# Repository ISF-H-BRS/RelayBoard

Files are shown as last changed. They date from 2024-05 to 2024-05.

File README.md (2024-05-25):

# ISF Relay Board

## Introduction
This repository contains schematics, PCB layout, firmware and software for a circuit board providing 16 software-programmable solid-state relays with individual voltage and current monitoring, every channel capable of switching up to 2 A at 32 V. It's original purpose was to allow control of various valves and pumps for chemical processes from within a LabVIEW program but it may also be useful for other automated control tasks.

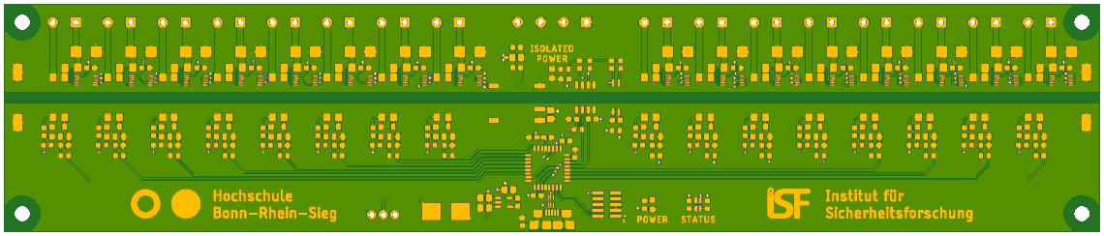
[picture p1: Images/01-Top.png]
TopView

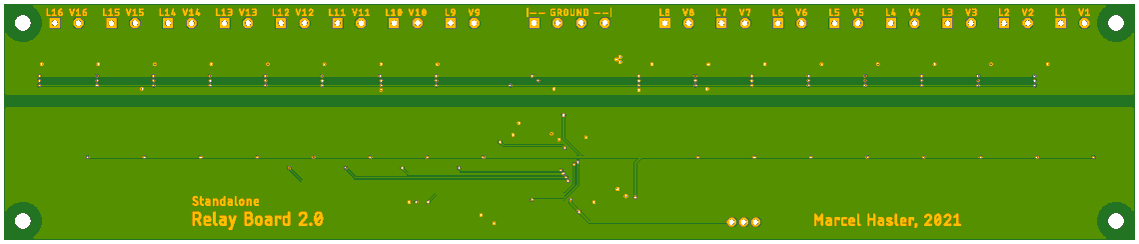
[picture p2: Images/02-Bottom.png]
BottomView


## Usage
The device uses a simple text-based protocol to communicate over a USB serial port. See Firmware/Protocol.txt for details. The protocol is also wrapped in a software library exposing both C++ and C interfaces, designed to allow it to be used from any programming language, including LabVIEW.

A Qt-based graphical example program is also provided that can be used to manually test all features of the device.

<p align="center">
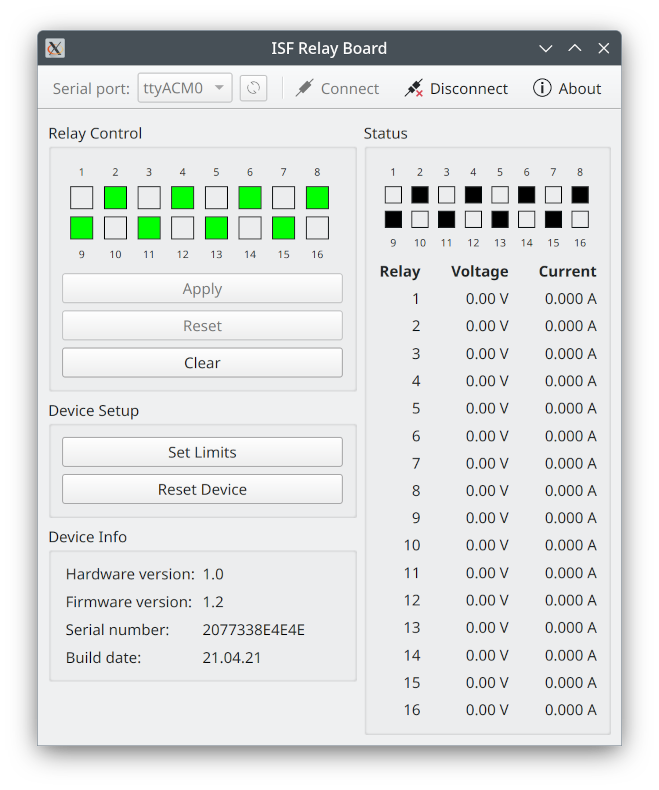
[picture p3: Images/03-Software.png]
  
</p>

## License
All source code for the software and firmware components, including the LabVIEW code, is licensed under the terms of the GNU General Public License (GPL). All schematics and layout files are licensed under the terms of the Creative Commons Attribution-ShareAlike International Public License (CC BY-SA). See COPYING in the respective subdirectories for details.

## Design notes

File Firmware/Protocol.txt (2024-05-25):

ISF RelayBoard - Communication Protocol
=======================================

Every transmission is ASCII-encoded and terminated by CR+LF (aka "\r\n").

Command Format
--------------

<COMMAND_TAG> [index] [argument1,argument2,...]

Response Format
---------------

<RESPONSE_TAG> [value1,value2,...]
or
<ERROR> code

Error Codes
-----------

DATA_OVERFLOW     Maximum transmission size of 100 characters exceeded
UNKNOWN_COMMAND   Command tag not recognized
MISSING_ARGUMENT  Insufficient number of arguments provided
INVALID_ARGUMENT  Invalid argument provided
ERASE_FAILED      Unable to erase flash memory page
WRITE_FAILED      Unable to write to flash memory

Commands
--------

RESET
Description: Resets fault and state masks
Index:       None
Arguments:   None
Example:     <RESET>
Response:    <OK>

GET_FAULT_MASK
Description: Returns bitmask (hex format) indicating overvoltage/-current
Index:       None
Arguments:   None
Example:     <GET_FAULT_MASK>
Response:    <FAULT_MASK> 0x0000

SET_RELAY_STATE
Description: Sets state of specified relay
Index:       0-15
Arguments:   New state (ON or OFF)
Examples:    <SET_RELAY_STATE> 0 ON
             <SET_RELAY_STATE> 0 OFF
Response:    <OK>

GET_RELAY_STATE
Description: Returns state of specified relay
Index:       0-15
Arguments:   None
Example:     <GET_RELAY_STATE> 0
Response:    <RELAY_STATE> OFF

SET_STATE_MASK
Description: Sets bitmask describing relay states
Index:       None
Arguments:   State mask (hex/decimal format)
Examples:    <SET_STATE_MASK> 0xaaaa
             <SET_STATE_MASK> 43690
Response:    <OK>

GET_STATE_MASK
Description: Returns bitmask (hex format) describing relay states
Index:       None
Arguments:   None
Example:     <GET_STATE_MASK>
Response:    <STATE_MASK> 0xaaaa

GET_RELAY_POWER
Description: Returns relay voltage in V and current in A
Index:       0-15
Arguments:   None
Example:     <GET_RELAY_POWER> 0
Response:    <RELAY_POWER> 12.34,1.234

SET_POWER_LIMIT
Description: Sets power limits for specified relay (max. 32 V @ 2 A)
Index:       0-15
Arguments:   Voltage limit in V, current limit in A
Example:     <SET_POWER_LIMIT> 0 16.00,1.000
Response:    <OK>

GET_POWER_LIMIT
Description: Returns currently set voltage limit in V and current limit in A
Index:       0-15
Arguments:   None
Example:     <GET_POWER_LIMIT> 0
Response:    <POWER_LIMIT> 16.00,1.000

SAVE_POWER_LIMITS
Description: Writes currently set limits to persistent flash memory
Index:       None
Arguments:   None
Example:     <SAVE_POWER_LIMITS>
Response:    <OK>

GET_HARDWARE_VERSION
Description: Returns hardware version
Index:       None
Arguments:   None
Example:     <GET_HARDWARE_VERSION>
Response:    <HARDWARE_VERSION> 1.0

GET_FIRMWARE_VERSION
Description: Returns firmware version
Index:       None
Arguments:   None
Example:     <GET_FIRMWARE_VERSION>
Response:    <FIRMWARE_VERSION> 1.0

GET_SERIAL_NUMBER
Description: Returns device serial number
Index:       None
Arguments:   None
Example:     <GET_SERIAL_NUMBER>
Response:    <SERIAL_NUMBER> 207733794E4E

GET_BUILD_TIMESTAMP
Description: Returns firmware build time as Unix time
Index:       None
Arguments:   None
Example:     <GET_BUILD_TIMESTAMP>
Response:    <BUILD_TIMESTAMP> 1618493589

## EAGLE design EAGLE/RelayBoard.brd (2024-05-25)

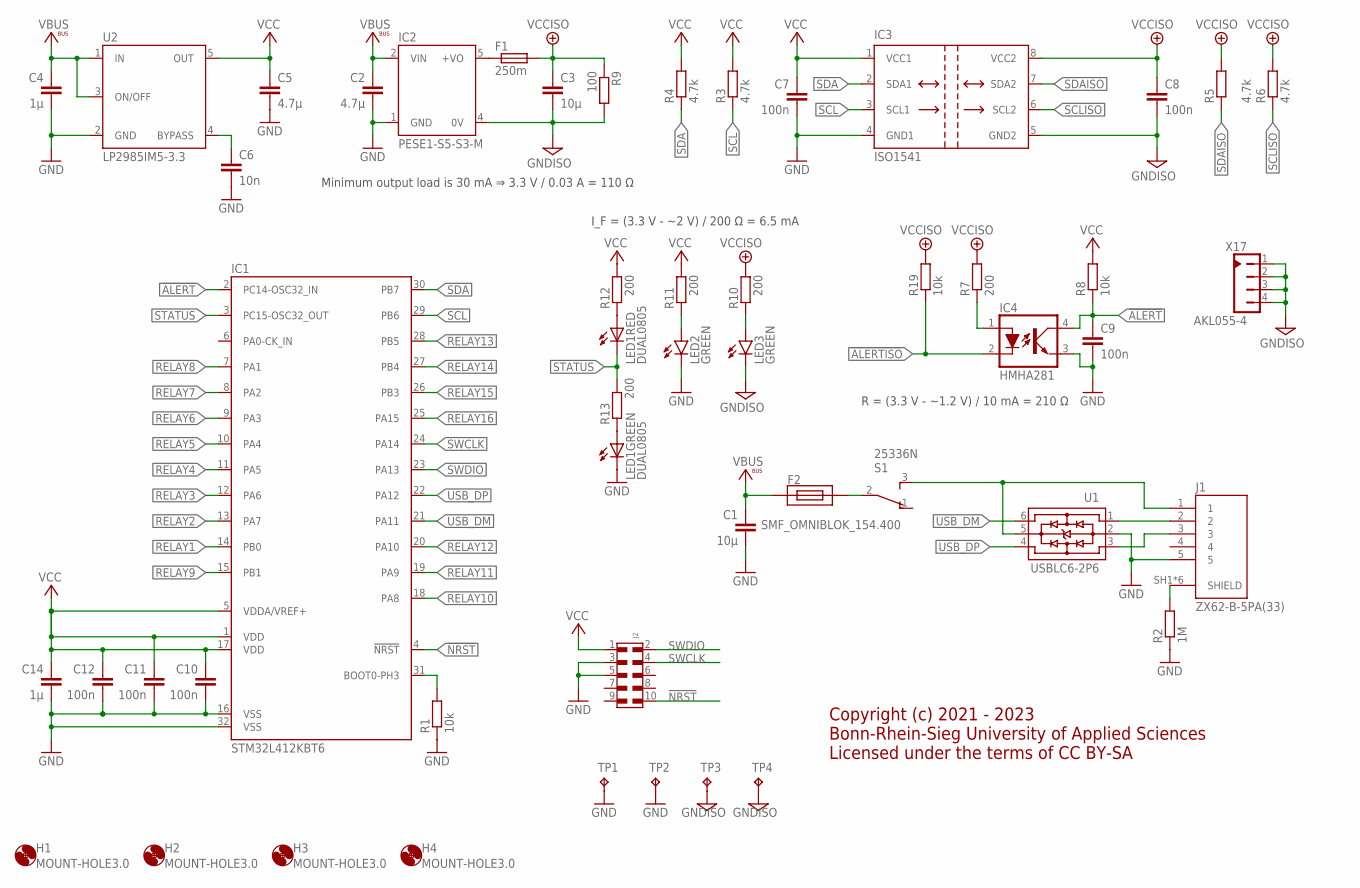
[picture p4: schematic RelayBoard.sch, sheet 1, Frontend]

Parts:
C1, C3: 10µ; C0805
C2, C5: 4.7µ; C0805
C4: 1µ; C0805
C6: 10n; C0603
C7, C8, C9, C10, C11, C12: 100n; C0603
C14: 1µ; C0603
F1: 250m; R0603
F2: SMF_OMNIBLOK_154.400; NANO2_SMF_FUSEBLOCK
H1, H2, H3, H4: MOUNT-HOLE3.0; 3,0
IC1: STM32L412KBT6; LQFP32
IC2: PESE1-S5-S3-M; PESE1-M
IC3: ISO1541; SOIC8
IC4: HMHA281; 4-MINI-FLAT
J1: ZX62-B-5PA(33); HRS_ZX62-B-5PA(33)
J2: 6210XX21021_62101021021; 62101021021
LED1: DUAL0805; CHIPLEDX2
LED2, LED3: GREEN; CHIPLED_0805
R1, R8, R19: 10k; R0603
R2: 1M; R0603
R3, R4, R5, R6: 4.7k; R0603
R7, R10, R11, R12, R13: 200; R0603
R9: 100; R0603
S1: 25336N; 2533XN
TP1, TP2, TP3, TP4: TP3.8X2.03; 3.8X2.03
U1: USBLC6-2P6; SOT-666
U2: LP2985IM5-3.3; SOT23-5
X17: AKL055-4

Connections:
!ALERT: C9.1, IC1.2 (PC14-OSC32_IN), IC4.4 (COLLECTOR), R8.1
!ALERTISO: IC4.2 (CATHODE), R19.1; also elsewhere on the board
!NRST: IC1.4 (!NRST), J2.10
GND: C1.2, C2.2, C4.2, C5.2, C6.2, C7.2, C9.2, C10.2, C11.2, C12.2, C14.2, IC1.16 (VSS), IC1.32 (VSS), IC2.1 (GND), IC3.4 (GND1), IC4.3 (EMITTER), J1.5, J2.3, J2.5, LED1.C2 (C), LED2.C, R1.1, R2.1, TP1.TP, TP2.TP, U1.2, U2.2 (GND); also elsewhere on the board
GNDISO: C3.2, C8.2, IC2.4 (0V), IC3.5 (GND2), LED3.C, R9.2, TP3.TP, TP4.TP, X17.1, X17.2, X17.3, X17.4; also elsewhere on the board
unnamed: J1.2, U1.1
unnamed: J1.3, U1.3
unnamed: J1.SH1 (SHIELD), J1.SH2 (SHIELD), J1.SH3 (SHIELD), J1.SH4 (SHIELD), J1.SH5 (SHIELD), J1.SH6 (SHIELD), R2.2
unnamed: IC4.1 (ANODE), R7.1
unnamed: C6.1, U2.4 (BYPASS)
unnamed: IC1.31 (BOOT0-PH3), R1.2
unnamed: LED3.A, R10.1
unnamed: LED2.A, R11.1
unnamed: LED1.A2 (A), R13.1
unnamed: LED1.A1 (A), R12.1
unnamed: J1.1, S1.3, U1.5
unnamed: F2.2, S1.2
unnamed: F1.1, IC2.5 (+VO)
RELAY1: IC1.14 (PB0); also elsewhere on the board
RELAY2: IC1.13 (PA7); also elsewhere on the board
RELAY3: IC1.12 (PA6); also elsewhere on the board
RELAY4: IC1.11 (PA5); also elsewhere on the board
RELAY5: IC1.10 (PA4); also elsewhere on the board
RELAY6: IC1.9 (PA3); also elsewhere on the board
RELAY7: IC1.8 (PA2); also elsewhere on the board
RELAY8: IC1.7 (PA1); also elsewhere on the board
RELAY9: IC1.15 (PB1); also elsewhere on the board
RELAY10: IC1.18 (PA8); also elsewhere on the board
RELAY11: IC1.19 (PA9); also elsewhere on the board
RELAY12: IC1.20 (PA10); also elsewhere on the board
RELAY13: IC1.28 (PB5); also elsewhere on the board
RELAY14: IC1.27 (PB4); also elsewhere on the board
RELAY15: IC1.26 (PB3); also elsewhere on the board
RELAY16: IC1.25 (PA15); also elsewhere on the board
SCL: IC1.29 (PB6), IC3.3 (SCL1), R3.1
SCLISO: IC3.6 (SCL2), R6.1; also elsewhere on the board
SDA: IC1.30 (PB7), IC3.2 (SDA1), R4.1
SDAISO: IC3.7 (SDA2), R5.1; also elsewhere on the board
STATUS: IC1.3 (PC15-OSC32_OUT), LED1.C1 (C), R13.2
SWCLK: IC1.24 (PA14), J2.4
SWDIO: IC1.23 (PA13), J2.2
USB_DM: IC1.21 (PA11), U1.6
USB_DP: IC1.22 (PA12), U1.4
VBUS: C1.1, C2.1, C4.1, F2.1, IC2.2 (VIN), U2.1 (IN), U2.3 (ON/OFF); also elsewhere on the board
VCC: C5.1, C7.1, C10.1, C11.1, C12.1, C14.1, IC1.1 (VDD), IC1.5 (VDDA/VREF+), IC1.17 (VDD), IC3.1 (VCC1), J2.1, R3.2, R4.2, R8.2, R11.2, R12.2, U2.5 (OUT)
VCCISO: C3.1, C8.1, F1.2, IC3.8 (VCC2), R5.2, R6.2, R7.2, R9.1, R10.2, R19.2; also elsewhere on the board

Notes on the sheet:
R = (3.3 V - ~1.2 V) / 10 mA = 210 Ω
Minimum output load is 30 mA ⇒ 3.3 V / 0.03 A = 110 Ω
I_F = (3.3 V - ~2 V) / 200 Ω = 6.5 mA
Copyright (c) 2021 - 2023 Bonn-Rhein-Sieg University of Applied Sciences Licensed under the terms of CC BY-SA

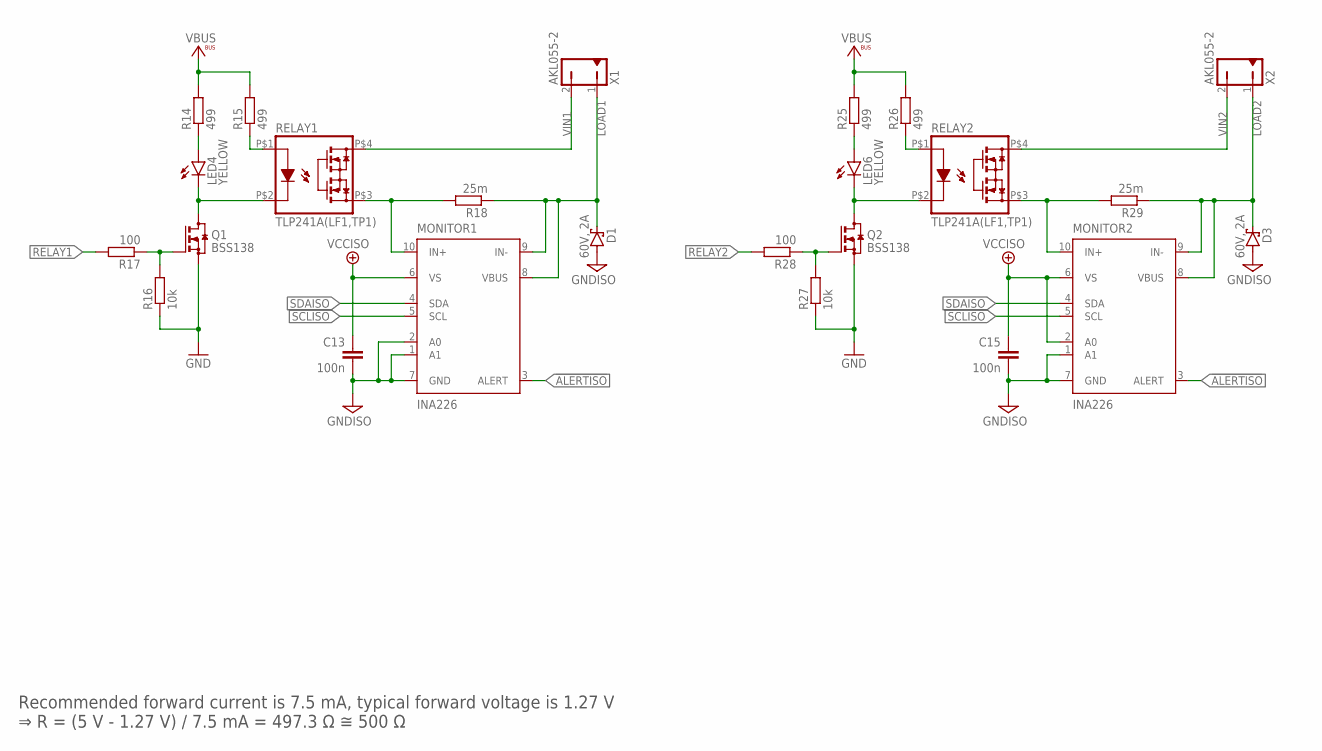
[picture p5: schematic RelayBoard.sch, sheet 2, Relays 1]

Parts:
C13, C15: 100n; C0603
D1, D3: 60V, 2A; SMB
LED4, LED6: YELLOW; CHIPLED_0805
MONITOR1, MONITOR2: INA226; MSOP10
Q1, Q2: BSS138; SOT23
R14, R15, R25, R26: 499; R0603
R16, R27: 10k; R0603
R17, R28: 100; R0603
R18, R29: 25m; R1206
RELAY1, RELAY2: TLP241A(LF1,TP1); TP1/5
X1, X2: AKL055-2

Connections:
!ALERTISO: MONITOR1.3 (ALERT), MONITOR2.3 (ALERT); also elsewhere on the board
GND: Q1.2 (S), Q2.2 (S), R16.1, R27.1; also elsewhere on the board
GNDISO: C13.2, C15.2, D1.A, D3.A, MONITOR1.1 (A1), MONITOR1.2 (A0), MONITOR1.7 (GND), MONITOR2.1 (A1), MONITOR2.7 (GND); also elsewhere on the board
LOAD1: D1.C, MONITOR1.8 (VBUS), MONITOR1.9 (IN-), R18.1, X1.1
LOAD2: D3.C, MONITOR2.8 (VBUS), MONITOR2.9 (IN-), R29.1, X2.1
unnamed: LED4.A, R14.1
unnamed: LED4.C, Q1.3 (D), RELAY1.P$2 (CATHODE)
unnamed: Q1.1 (G), R16.2, R17.1
unnamed: MONITOR1.10 (IN+), R18.2, RELAY1.P$3 (DRAIN1)
unnamed: R15.1, RELAY1.P$1 (ANODE)
unnamed: LED6.A, R25.1
unnamed: LED6.C, Q2.3 (D), RELAY2.P$2 (CATHODE)
unnamed: Q2.1 (G), R27.2, R28.1
unnamed: MONITOR2.10 (IN+), R29.2, RELAY2.P$3 (DRAIN1)
unnamed: R26.1, RELAY2.P$1 (ANODE)
RELAY1: R17.2; also elsewhere on the board
RELAY2: R28.2; also elsewhere on the board
SCLISO: MONITOR1.5 (SCL), MONITOR2.5 (SCL); also elsewhere on the board
SDAISO: MONITOR1.4 (SDA), MONITOR2.4 (SDA); also elsewhere on the board
VBUS: R14.2, R15.2, R25.2, R26.2; also elsewhere on the board
VCCISO: C13.1, C15.1, MONITOR1.6 (VS), MONITOR2.2 (A0), MONITOR2.6 (VS); also elsewhere on the board
VIN1: RELAY1.P$4 (DRAIN2), X1.2 (4)
VIN2: RELAY2.P$4 (DRAIN2), X2.2 (4)

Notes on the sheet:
Recommended forward current is 7.5 mA, typical forward voltage is 1.27 V ⇒ R = (5 V - 1.27 V) / 7.5 mA = 497.3 Ω ≅ 500 Ω

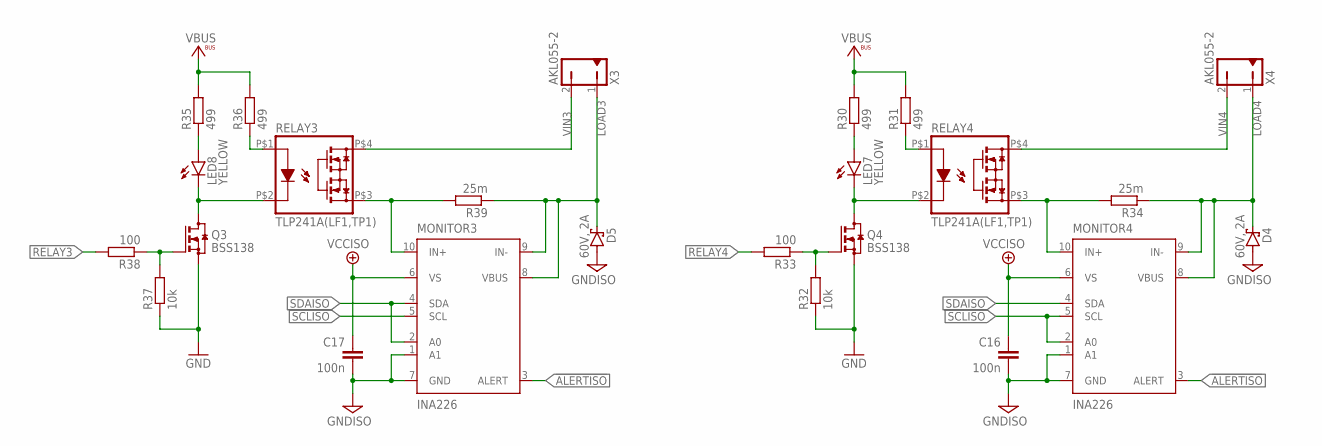
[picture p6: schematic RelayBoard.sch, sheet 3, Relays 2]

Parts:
C16, C17: 100n; C0603
D4, D5: 60V, 2A; SMB
LED7, LED8: YELLOW; CHIPLED_0805
MONITOR3, MONITOR4: INA226; MSOP10
Q3, Q4: BSS138; SOT23
R30, R31, R35, R36: 499; R0603
R32, R37: 10k; R0603
R33, R38: 100; R0603
R34, R39: 25m; R1206
RELAY3, RELAY4: TLP241A(LF1,TP1); TP1/5
X3, X4: AKL055-2

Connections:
!ALERTISO: MONITOR3.3 (ALERT), MONITOR4.3 (ALERT); also elsewhere on the board
GND: Q3.2 (S), Q4.2 (S), R32.1, R37.1; also elsewhere on the board
GNDISO: C16.2, C17.2, D4.A, D5.A, MONITOR3.1 (A1), MONITOR3.7 (GND), MONITOR4.1 (A1), MONITOR4.7 (GND); also elsewhere on the board
LOAD3: D5.C, MONITOR3.8 (VBUS), MONITOR3.9 (IN-), R39.1, X3.1
LOAD4: D4.C, MONITOR4.8 (VBUS), MONITOR4.9 (IN-), R34.1, X4.1
unnamed: LED7.A, R30.1
unnamed: LED7.C, Q4.3 (D), RELAY4.P$2 (CATHODE)
unnamed: Q4.1 (G), R32.2, R33.1
unnamed: MONITOR4.10 (IN+), R34.2, RELAY4.P$3 (DRAIN1)
unnamed: R31.1, RELAY4.P$1 (ANODE)
unnamed: LED8.A, R35.1
unnamed: LED8.C, Q3.3 (D), RELAY3.P$2 (CATHODE)
unnamed: Q3.1 (G), R37.2, R38.1
unnamed: MONITOR3.10 (IN+), R39.2, RELAY3.P$3 (DRAIN1)
unnamed: R36.1, RELAY3.P$1 (ANODE)
RELAY3: R38.2; also elsewhere on the board
RELAY4: R33.2; also elsewhere on the board
SCLISO: MONITOR3.5 (SCL), MONITOR4.2 (A0), MONITOR4.5 (SCL); also elsewhere on the board
SDAISO: MONITOR3.2 (A0), MONITOR3.4 (SDA), MONITOR4.4 (SDA); also elsewhere on the board
VBUS: R30.2, R31.2, R35.2, R36.2; also elsewhere on the board
VCCISO: C16.1, C17.1, MONITOR3.6 (VS), MONITOR4.6 (VS); also elsewhere on the board
VIN3: RELAY3.P$4 (DRAIN2), X3.2 (4)
VIN4: RELAY4.P$4 (DRAIN2), X4.2 (4)

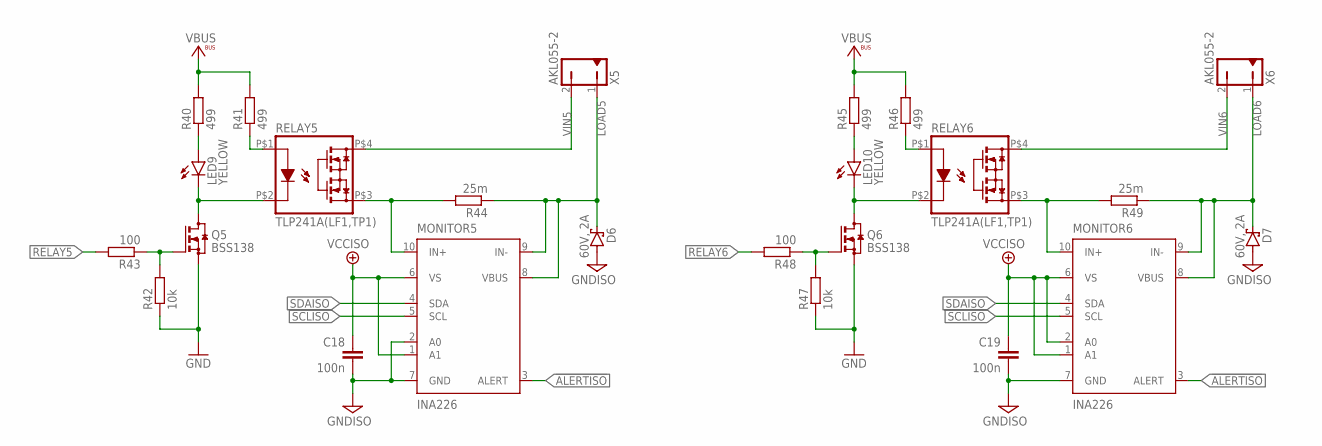
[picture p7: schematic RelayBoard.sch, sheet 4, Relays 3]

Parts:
C18, C19: 100n; C0603
D6, D7: 60V, 2A; SMB
LED9, LED10: YELLOW; CHIPLED_0805
MONITOR5, MONITOR6: INA226; MSOP10
Q5, Q6: BSS138; SOT23
R40, R41, R45, R46: 499; R0603
R42, R47: 10k; R0603
R43, R48: 100; R0603
R44, R49: 25m; R1206
RELAY5, RELAY6: TLP241A(LF1,TP1); TP1/5
X5, X6: AKL055-2

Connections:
!ALERTISO: MONITOR5.3 (ALERT), MONITOR6.3 (ALERT); also elsewhere on the board
GND: Q5.2 (S), Q6.2 (S), R42.1, R47.1; also elsewhere on the board
GNDISO: C18.2, C19.2, D6.A, D7.A, MONITOR5.2 (A0), MONITOR5.7 (GND), MONITOR6.7 (GND); also elsewhere on the board
LOAD5: D6.C, MONITOR5.8 (VBUS), MONITOR5.9 (IN-), R44.1, X5.1
LOAD6: D7.C, MONITOR6.8 (VBUS), MONITOR6.9 (IN-), R49.1, X6.1
unnamed: LED9.A, R40.1
unnamed: LED9.C, Q5.3 (D), RELAY5.P$2 (CATHODE)
unnamed: Q5.1 (G), R42.2, R43.1
unnamed: MONITOR5.10 (IN+), R44.2, RELAY5.P$3 (DRAIN1)
unnamed: R41.1, RELAY5.P$1 (ANODE)
unnamed: LED10.A, R45.1
unnamed: LED10.C, Q6.3 (D), RELAY6.P$2 (CATHODE)
unnamed: Q6.1 (G), R47.2, R48.1
unnamed: MONITOR6.10 (IN+), R49.2, RELAY6.P$3 (DRAIN1)
unnamed: R46.1, RELAY6.P$1 (ANODE)
RELAY5: R43.2; also elsewhere on the board
RELAY6: R48.2; also elsewhere on the board
SCLISO: MONITOR5.5 (SCL), MONITOR6.5 (SCL); also elsewhere on the board
SDAISO: MONITOR5.4 (SDA), MONITOR6.4 (SDA); also elsewhere on the board
VBUS: R40.2, R41.2, R45.2, R46.2; also elsewhere on the board
VCCISO: C18.1, C19.1, MONITOR5.1 (A1), MONITOR5.6 (VS), MONITOR6.1 (A1), MONITOR6.2 (A0), MONITOR6.6 (VS); also elsewhere on the board
VIN5: RELAY5.P$4 (DRAIN2), X5.2 (4)
VIN6: RELAY6.P$4 (DRAIN2), X6.2 (4)

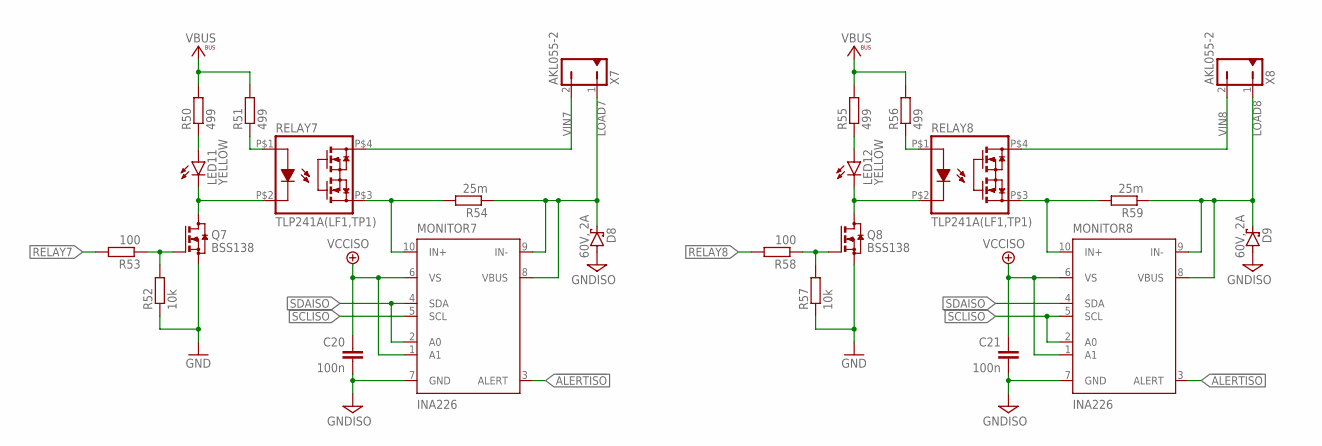
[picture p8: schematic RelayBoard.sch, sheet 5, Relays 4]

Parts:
C20, C21: 100n; C0603
D8, D9: 60V, 2A; SMB
LED11, LED12: YELLOW; CHIPLED_0805
MONITOR7, MONITOR8: INA226; MSOP10
Q7, Q8: BSS138; SOT23
R50, R51, R55, R56: 499; R0603
R52, R57: 10k; R0603
R53, R58: 100; R0603
R54, R59: 25m; R1206
RELAY7, RELAY8: TLP241A(LF1,TP1); TP1/5
X7, X8: AKL055-2

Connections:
!ALERTISO: MONITOR7.3 (ALERT), MONITOR8.3 (ALERT); also elsewhere on the board
GND: Q7.2 (S), Q8.2 (S), R52.1, R57.1; also elsewhere on the board
GNDISO: C20.2, C21.2, D8.A, D9.A, MONITOR7.7 (GND), MONITOR8.7 (GND); also elsewhere on the board
LOAD7: D8.C, MONITOR7.8 (VBUS), MONITOR7.9 (IN-), R54.1, X7.1
LOAD8: D9.C, MONITOR8.8 (VBUS), MONITOR8.9 (IN-), R59.1, X8.1
unnamed: LED11.A, R50.1
unnamed: LED11.C, Q7.3 (D), RELAY7.P$2 (CATHODE)
unnamed: Q7.1 (G), R52.2, R53.1
unnamed: MONITOR7.10 (IN+), R54.2, RELAY7.P$3 (DRAIN1)
unnamed: R51.1, RELAY7.P$1 (ANODE)
unnamed: LED12.A, R55.1
unnamed: LED12.C, Q8.3 (D), RELAY8.P$2 (CATHODE)
unnamed: Q8.1 (G), R57.2, R58.1
unnamed: MONITOR8.10 (IN+), R59.2, RELAY8.P$3 (DRAIN1)
unnamed: R56.1, RELAY8.P$1 (ANODE)
RELAY7: R53.2; also elsewhere on the board
RELAY8: R58.2; also elsewhere on the board
SCLISO: MONITOR7.5 (SCL), MONITOR8.2 (A0), MONITOR8.5 (SCL); also elsewhere on the board
SDAISO: MONITOR7.2 (A0), MONITOR7.4 (SDA), MONITOR8.4 (SDA); also elsewhere on the board
VBUS: R50.2, R51.2, R55.2, R56.2; also elsewhere on the board
VCCISO: C20.1, C21.1, MONITOR7.1 (A1), MONITOR7.6 (VS), MONITOR8.1 (A1), MONITOR8.6 (VS); also elsewhere on the board
VIN7: RELAY7.P$4 (DRAIN2), X7.2 (4)
VIN8: RELAY8.P$4 (DRAIN2), X8.2 (4)

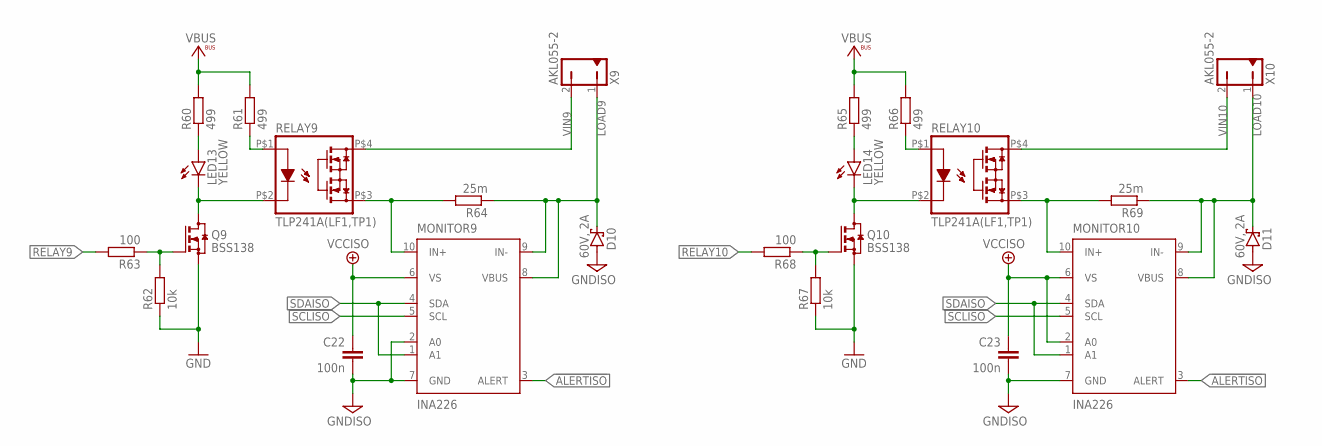
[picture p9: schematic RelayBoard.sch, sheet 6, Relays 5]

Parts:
C22, C23: 100n; C0603
D10, D11: 60V, 2A; SMB
LED13, LED14: YELLOW; CHIPLED_0805
MONITOR9, MONITOR10: INA226; MSOP10
Q9, Q10: BSS138; SOT23
R60, R61, R65, R66: 499; R0603
R62, R67: 10k; R0603
R63, R68: 100; R0603
R64, R69: 25m; R1206
RELAY9, RELAY10: TLP241A(LF1,TP1); TP1/5
X9, X10: AKL055-2

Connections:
!ALERTISO: MONITOR9.3 (ALERT), MONITOR10.3 (ALERT); also elsewhere on the board
GND: Q9.2 (S), Q10.2 (S), R62.1, R67.1; also elsewhere on the board
GNDISO: C22.2, C23.2, D10.A, D11.A, MONITOR9.2 (A0), MONITOR9.7 (GND), MONITOR10.7 (GND); also elsewhere on the board
LOAD9: D10.C, MONITOR9.8 (VBUS), MONITOR9.9 (IN-), R64.1, X9.1
LOAD10: D11.C, MONITOR10.8 (VBUS), MONITOR10.9 (IN-), R69.1, X10.1
unnamed: LED13.A, R60.1
unnamed: LED13.C, Q9.3 (D), RELAY9.P$2 (CATHODE)
unnamed: Q9.1 (G), R62.2, R63.1
unnamed: MONITOR9.10 (IN+), R64.2, RELAY9.P$3 (DRAIN1)
unnamed: R61.1, RELAY9.P$1 (ANODE)
unnamed: LED14.A, R65.1
unnamed: LED14.C, Q10.3 (D), RELAY10.P$2 (CATHODE)
unnamed: Q10.1 (G), R67.2, R68.1
unnamed: MONITOR10.10 (IN+), R69.2, RELAY10.P$3 (DRAIN1)
unnamed: R66.1, RELAY10.P$1 (ANODE)
RELAY9: R63.2; also elsewhere on the board
RELAY10: R68.2; also elsewhere on the board
SCLISO: MONITOR9.5 (SCL), MONITOR10.5 (SCL); also elsewhere on the board
SDAISO: MONITOR9.1 (A1), MONITOR9.4 (SDA), MONITOR10.1 (A1), MONITOR10.4 (SDA); also elsewhere on the board
VBUS: R60.2, R61.2, R65.2, R66.2; also elsewhere on the board
VCCISO: C22.1, C23.1, MONITOR9.6 (VS), MONITOR10.2 (A0), MONITOR10.6 (VS); also elsewhere on the board
VIN9: RELAY9.P$4 (DRAIN2), X9.2 (4)
VIN10: RELAY10.P$4 (DRAIN2), X10.2 (4)

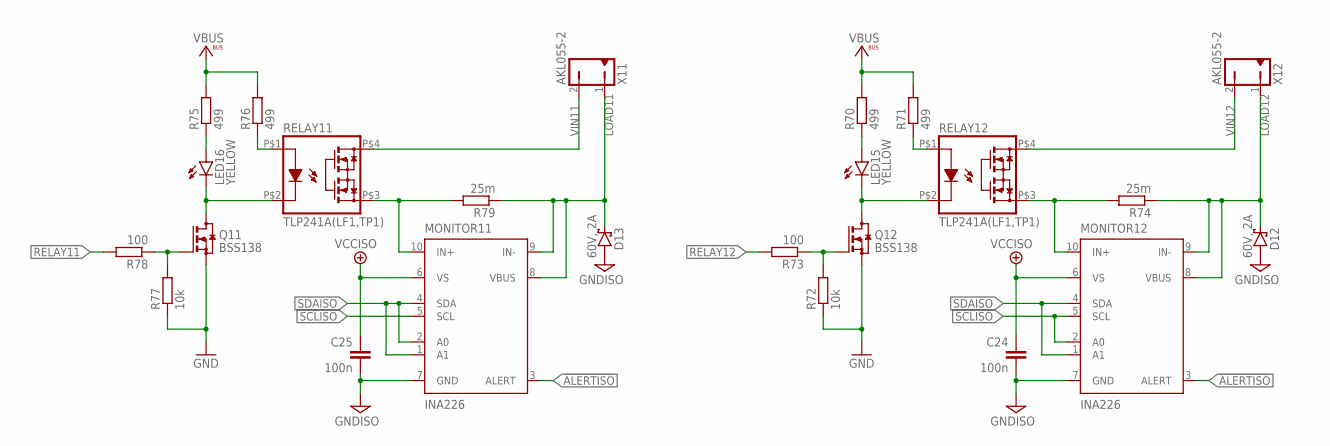
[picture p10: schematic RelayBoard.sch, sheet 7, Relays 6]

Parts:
C24, C25: 100n; C0603
D12, D13: 60V, 2A; SMB
LED15, LED16: YELLOW; CHIPLED_0805
MONITOR11, MONITOR12: INA226; MSOP10
Q11, Q12: BSS138; SOT23
R70, R71, R75, R76: 499; R0603
R72, R77: 10k; R0603
R73, R78: 100; R0603
R74, R79: 25m; R1206
RELAY11, RELAY12: TLP241A(LF1,TP1); TP1/5
X11, X12: AKL055-2

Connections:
!ALERTISO: MONITOR11.3 (ALERT), MONITOR12.3 (ALERT); also elsewhere on the board
GND: Q11.2 (S), Q12.2 (S), R72.1, R77.1; also elsewhere on the board
GNDISO: C24.2, C25.2, D12.A, D13.A, MONITOR11.7 (GND), MONITOR12.7 (GND); also elsewhere on the board
LOAD11: D13.C, MONITOR11.8 (VBUS), MONITOR11.9 (IN-), R79.1, X11.1
LOAD12: D12.C, MONITOR12.8 (VBUS), MONITOR12.9 (IN-), R74.1, X12.1
unnamed: LED15.A, R70.1
unnamed: LED15.C, Q12.3 (D), RELAY12.P$2 (CATHODE)
unnamed: Q12.1 (G), R72.2, R73.1
unnamed: MONITOR12.10 (IN+), R74.2, RELAY12.P$3 (DRAIN1)
unnamed: R71.1, RELAY12.P$1 (ANODE)
unnamed: LED16.A, R75.1
unnamed: LED16.C, Q11.3 (D), RELAY11.P$2 (CATHODE)
unnamed: Q11.1 (G), R77.2, R78.1
unnamed: MONITOR11.10 (IN+), R79.2, RELAY11.P$3 (DRAIN1)
unnamed: R76.1, RELAY11.P$1 (ANODE)
RELAY11: R78.2; also elsewhere on the board
RELAY12: R73.2; also elsewhere on the board
SCLISO: MONITOR11.5 (SCL), MONITOR12.2 (A0), MONITOR12.5 (SCL); also elsewhere on the board
SDAISO: MONITOR11.1 (A1), MONITOR11.2 (A0), MONITOR11.4 (SDA), MONITOR12.1 (A1), MONITOR12.4 (SDA); also elsewhere on the board
VBUS: R70.2, R71.2, R75.2, R76.2; also elsewhere on the board
VCCISO: C24.1, C25.1, MONITOR11.6 (VS), MONITOR12.6 (VS); also elsewhere on the board
VIN11: RELAY11.P$4 (DRAIN2), X11.2 (4)
VIN12: RELAY12.P$4 (DRAIN2), X12.2 (4)

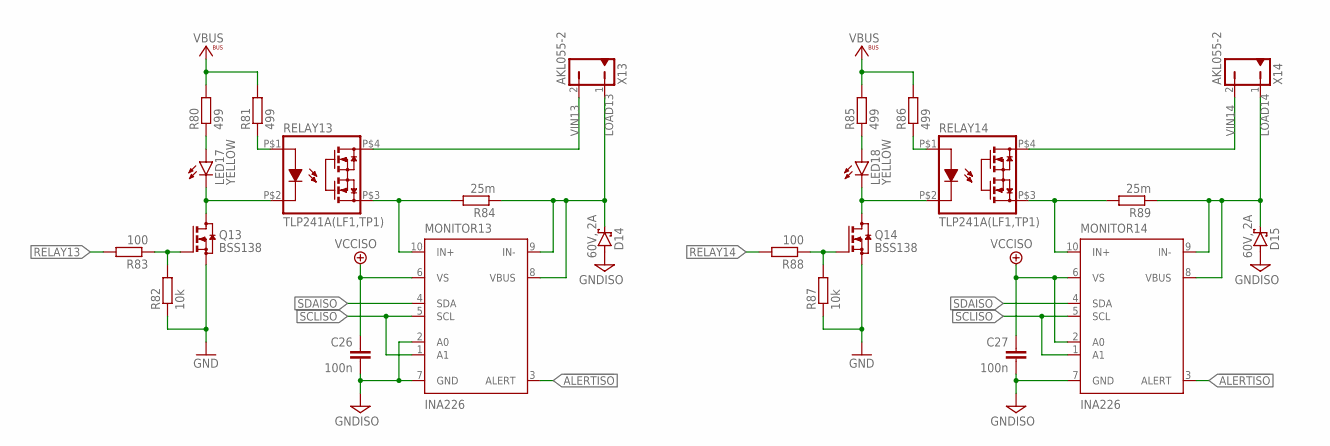
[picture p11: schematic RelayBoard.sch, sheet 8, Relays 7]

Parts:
C26, C27: 100n; C0603
D14, D15: 60V, 2A; SMB
LED17, LED18: YELLOW; CHIPLED_0805
MONITOR13, MONITOR14: INA226; MSOP10
Q13, Q14: BSS138; SOT23
R80, R81, R85, R86: 499; R0603
R82, R87: 10k; R0603
R83, R88: 100; R0603
R84, R89: 25m; R1206
RELAY13, RELAY14: TLP241A(LF1,TP1); TP1/5
X13, X14: AKL055-2

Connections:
!ALERTISO: MONITOR13.3 (ALERT), MONITOR14.3 (ALERT); also elsewhere on the board
GND: Q13.2 (S), Q14.2 (S), R82.1, R87.1; also elsewhere on the board
GNDISO: C26.2, C27.2, D14.A, D15.A, MONITOR13.2 (A0), MONITOR13.7 (GND), MONITOR14.7 (GND); also elsewhere on the board
LOAD13: D14.C, MONITOR13.8 (VBUS), MONITOR13.9 (IN-), R84.1, X13.1
LOAD14: D15.C, MONITOR14.8 (VBUS), MONITOR14.9 (IN-), R89.1, X14.1
unnamed: LED17.A, R80.1
unnamed: LED17.C, Q13.3 (D), RELAY13.P$2 (CATHODE)
unnamed: Q13.1 (G), R82.2, R83.1
unnamed: MONITOR13.10 (IN+), R84.2, RELAY13.P$3 (DRAIN1)
unnamed: R81.1, RELAY13.P$1 (ANODE)
unnamed: LED18.A, R85.1
unnamed: LED18.C, Q14.3 (D), RELAY14.P$2 (CATHODE)
unnamed: Q14.1 (G), R87.2, R88.1
unnamed: MONITOR14.10 (IN+), R89.2, RELAY14.P$3 (DRAIN1)
unnamed: R86.1, RELAY14.P$1 (ANODE)
RELAY13: R83.2; also elsewhere on the board
RELAY14: R88.2; also elsewhere on the board
SCLISO: MONITOR13.1 (A1), MONITOR13.5 (SCL), MONITOR14.1 (A1), MONITOR14.5 (SCL); also elsewhere on the board
SDAISO: MONITOR13.4 (SDA), MONITOR14.4 (SDA); also elsewhere on the board
VBUS: R80.2, R81.2, R85.2, R86.2; also elsewhere on the board
VCCISO: C26.1, C27.1, MONITOR13.6 (VS), MONITOR14.2 (A0), MONITOR14.6 (VS); also elsewhere on the board
VIN13: RELAY13.P$4 (DRAIN2), X13.2 (4)
VIN14: RELAY14.P$4 (DRAIN2), X14.2 (4)

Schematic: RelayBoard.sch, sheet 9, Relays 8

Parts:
C28, C30: 100n; C0603
D16, D18: 60V, 2A; SMB
LED19, LED21: YELLOW; CHIPLED_0805
MONITOR15, MONITOR16: INA226; MSOP10
Q15, Q16: BSS138; SOT23
R90, R91, R100, R101: 499; R0603
R92, R102: 10k; R0603
R93, R103: 100; R0603
R94, R104: 25m; R1206
RELAY15, RELAY16: TLP241A(LF1,TP1); TP1/5
X15, X16: AKL055-2

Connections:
!ALERTISO: MONITOR15.3 (ALERT), MONITOR16.3 (ALERT); also elsewhere on the board
GND: Q15.2 (S), Q16.2 (S), R92.1, R102.1; also elsewhere on the board
GNDISO: C28.2, C30.2, D16.A, D18.A, MONITOR15.7 (GND), MONITOR16.7 (GND); also elsewhere on the board
LOAD15: D16.C, MONITOR15.8 (VBUS), MONITOR15.9 (IN-), R94.1, X15.1
LOAD16: D18.C, MONITOR16.8 (VBUS), MONITOR16.9 (IN-), R104.1, X16.1
unnamed: LED19.A, R90.1
unnamed: LED19.C, Q15.3 (D), RELAY15.P$2 (CATHODE)
unnamed: Q15.1 (G), R92.2, R93.1
unnamed: MONITOR15.10 (IN+), R94.2, RELAY15.P$3 (DRAIN1)
unnamed: R91.1, RELAY15.P$1 (ANODE)
unnamed: LED21.A, R100.1
unnamed: LED21.C, Q16.3 (D), RELAY16.P$2 (CATHODE)
unnamed: Q16.1 (G), R102.2, R103.1
unnamed: MONITOR16.10 (IN+), R104.2, RELAY16.P$3 (DRAIN1)
unnamed: R101.1, RELAY16.P$1 (ANODE)
RELAY15: R93.2; also elsewhere on the board
RELAY16: R103.2; also elsewhere on the board
SCLISO: MONITOR15.1 (A1), MONITOR15.5 (SCL), MONITOR16.1 (A1), MONITOR16.2 (A0), MONITOR16.5 (SCL); also elsewhere on the board
SDAISO: MONITOR15.2 (A0), MONITOR15.4 (SDA), MONITOR16.4 (SDA); also elsewhere on the board
VBUS: R90.2, R91.2, R100.2, R101.2; also elsewhere on the board
VCCISO: C28.1, C30.1, MONITOR15.6 (VS), MONITOR16.6 (VS); also elsewhere on the board
VIN15: RELAY15.P$4 (DRAIN2), X15.2 (4)
VIN16: RELAY16.P$4 (DRAIN2), X16.2 (4)

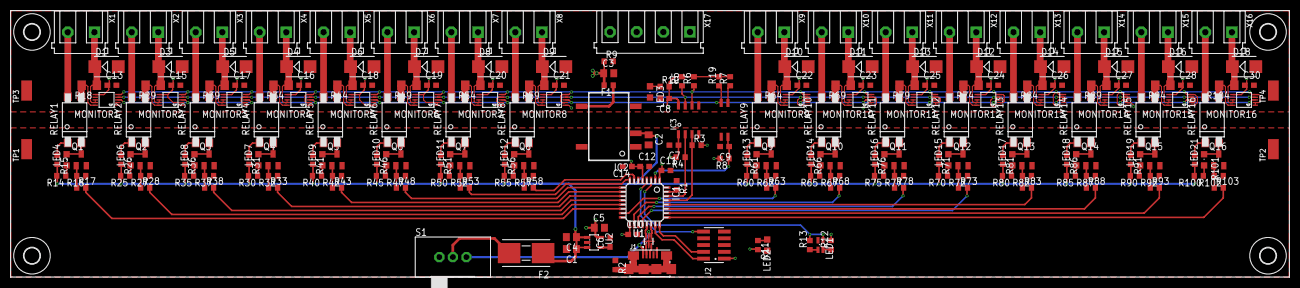
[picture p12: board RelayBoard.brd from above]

Board: 2 copper layers, 240.0 x 50.0 mm, 242 parts (0 on the bottom side), 158 nets.

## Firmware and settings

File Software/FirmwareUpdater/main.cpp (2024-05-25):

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
#include "mainwindow.h"

#include <FirmwareUpdater/core.h>

#include <QApplication>

// ---------------------------------------------------------------------------------------------- //

namespace {
    constexpr const char* PublicKey =
            "-----BEGIN RSA PUBLIC KEY-----\n"
            "MIICIjANBgkqhkiG9w0BAQEFAAOCAg8AMIICCgKCAgEAwEMfzV5lWIkCOys5d5tU\n"
            "qf7p21PRQEYbnKZPauPe+bzDIesWfauqKpYBm85Mx7Kb3p3IXXKJDgUu/gZxX6zw\n"
            "wr7VQUS4y4GDmsZWmkI54MVGw56l5NXONVPo8j//XTiQKpjalUIq2MYr/sqzW9lR\n"
            "FzTdEs7T6YQqFfGAhiUMuf/5y+4gV7kkE3KSmPz6WR0XNCRr4EALvSeo2jiAmi9d\n"
            "HooQJ9R9gj1fCDyIIuPz6SPdFEnwXIl3VEpP01zUJ5Wd5tIEuD9Nq9ZW2QqgC1pW\n"
            "0SXNvKqq+viMfxalW0Vm2cgDa202NTvx1c9CXKpPN5u3Y1GarMAsxRraaENaMWfQ\n"
            "ITxCp++pMWdC+cwV3U5V0XCaZvcaNe1LZsRP7zr7BV5Ori+Bx6LG2hHO1xwUSkgB\n"
            "IQwWwXWm46mXLs+F4nBCiwu5KFS/sGlgB00SBg3RtL/OsExdl3ocTQnvgsScq3hv\n"
            "aZ8DleH2Cq7ibW3qyMPOtlry7S6SMQ3vaa6ARX0Uiok4+KgPIE3i97JwD8fzcIHV\n"
            "LBH0BRxY26kBVJdQP7VC79fSgkQNOEgXEpORlHqZnq0v0GzJnpk5hQZFZ7CzmlRO\n"
            "YmKZhB/f+veEoS9fqO5V91nJbXN+mKIAnp0SEHS+XEPWlztJIDaRnqebnNkOof5M\n"
            "25xtUa27iYQUaLGh6N4XBwkCAwEAAQ==\n"
            "-----END RSA PUBLIC KEY-----\n";
}

// ---------------------------------------------------------------------------------------------- //

auto main(int argc, char* argv[]) -> int
{
    FirmwareUpdater::FirmwareArchive::registerPublicKey("ISF", PublicKey);

    QCoreApplication::setOrganizationName("Bonn-Rhein-Sieg University of Applied Sciences");
    QCoreApplication::setApplicationName("IRB Firmware Updater");
    QCoreApplication::setApplicationVersion("1.0");

    QApplication application(argc, argv);

    MainWindow window;
    window.show();

    return QApplication::exec();
}

// ---------------------------------------------------------------------------------------------- //

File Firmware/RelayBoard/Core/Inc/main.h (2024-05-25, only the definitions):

#define ALERT_Pin GPIO_PIN_14
#define ALERT_GPIO_Port GPIOC
#define STATUS_Pin GPIO_PIN_15
#define STATUS_GPIO_Port GPIOC
#define RELAY08_Pin GPIO_PIN_1
#define RELAY08_GPIO_Port GPIOA
#define RELAY07_Pin GPIO_PIN_2
#define RELAY07_GPIO_Port GPIOA
#define RELAY06_Pin GPIO_PIN_3
#define RELAY06_GPIO_Port GPIOA
#define RELAY05_Pin GPIO_PIN_4
#define RELAY05_GPIO_Port GPIOA
#define RELAY04_Pin GPIO_PIN_5
#define RELAY04_GPIO_Port GPIOA
#define RELAY03_Pin GPIO_PIN_6
#define RELAY03_GPIO_Port GPIOA
#define RELAY02_Pin GPIO_PIN_7
#define RELAY02_GPIO_Port GPIOA
#define RELAY01_Pin GPIO_PIN_0
#define RELAY01_GPIO_Port GPIOB
#define RELAY09_Pin GPIO_PIN_1
#define RELAY09_GPIO_Port GPIOB
#define RELAY10_Pin GPIO_PIN_8
#define RELAY10_GPIO_Port GPIOA
#define RELAY11_Pin GPIO_PIN_9
#define RELAY11_GPIO_Port GPIOA
#define RELAY12_Pin GPIO_PIN_10
#define RELAY12_GPIO_Port GPIOA
#define SWDIO_Pin GPIO_PIN_13
#define SWDIO_GPIO_Port GPIOA
#define SWCLK_Pin GPIO_PIN_14
#define SWCLK_GPIO_Port GPIOA
#define RELAY16_Pin GPIO_PIN_15
#define RELAY16_GPIO_Port GPIOA
#define RELAY15_Pin GPIO_PIN_3
#define RELAY15_GPIO_Port GPIOB
#define RELAY14_Pin GPIO_PIN_4
#define RELAY14_GPIO_Port GPIOB
#define RELAY13_Pin GPIO_PIN_5
#define RELAY13_GPIO_Port GPIOB
#define SCL_Pin GPIO_PIN_6
#define SCL_GPIO_Port GPIOB
#define SDA_Pin GPIO_PIN_7
#define SDA_GPIO_Port GPIOB

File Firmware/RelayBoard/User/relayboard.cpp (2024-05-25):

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
#include "config.h"
#include "main.h"
#include "relayboard.h"
#include "timestamp.h"

#include "usbd_desc.h"

// ---------------------------------------------------------------------------------------------- //

namespace {
    constexpr char TokenSeparator = ' ';

    constexpr uint32_t BootloaderMagic = 0xdeadbeef;
    volatile uint32_t g_bootloaderMagic __attribute__((section(".bootflags")));
}

// ---------------------------------------------------------------------------------------------- //

class MissingArgumentError : public std::exception
{
public:
    auto what() const noexcept -> const char* { return "MISSING_ARGUMENT"; }
};

// ---------------------------------------------------------------------------------------------- //

class InvalidArgumentError : public std::exception
{
public:
    auto what() const noexcept -> const char* { return "INVALID_ARGUMENT"; }
};

// ---------------------------------------------------------------------------------------------- //

RelayBoard::RelayBoard()
    : m_hostInterface(this),
      m_relayManager(this)
{
}

// ---------------------------------------------------------------------------------------------- //

void RelayBoard::exec()
{
    HAL_GPIO_WritePin(STATUS_GPIO_Port, STATUS_Pin, GPIO_PIN_SET);

    while (true)
    {
        m_hostInterface.update();
        m_relayManager.update();
    }
}

// ---------------------------------------------------------------------------------------------- //

void RelayBoard::onHostDataReceived(const String& data)
{
    const size_t tokenCount = data.countTokens(TokenSeparator);

    if (tokenCount < 1)
        return;

    const String tag = data.getToken(TokenSeparator, 0);

    if (tag == "<GET_FAULT_MASK>")
        protocolGetFaultMask();
    else if (tag == "<SET_RELAY_STATE>")
        protocolSetRelayState(data, tokenCount);
    else if (tag == "<GET_RELAY_STATE>")
        protocolGetRelayState(data, tokenCount);
    else if (tag == "<SET_STATE_MASK>")
        protocolSetStateMask(data, tokenCount);
    else if (tag == "<GET_STATE_MASK>")
        protocolGetStateMask();
    else if (tag == "<GET_RELAY_POWER>")
        protocolGetRelayPower(data, tokenCount);
    else if (tag == "<SET_POWER_LIMIT>")
        protocolSetPowerLimit(data, tokenCount);
    else if (tag == "<GET_POWER_LIMIT>")
        protocolGetPowerLimit(data, tokenCount);
    else if (tag == "<SAVE_POWER_LIMITS>")
        protocolSavePowerLimits();
    else if (tag == "<RESET>")
        protocolReset();
    else if (tag == "<GET_BOOT_MODE>")
        protocolGetBootMode();
    else if (tag == "<GET_BOARD_NAME>")
        protocolGetBoardName();
    else if (tag == "<GET_HARDWARE_VERSION>")
        protocolGetHardwareVersion();
    else if (tag == "<GET_FIRMWARE_VERSION>")
        protocolGetFirmwareVersion();
    else if (tag == "<GET_SERIAL_NUMBER>")
        protocolGetSerialNumber();
    else if (tag == "<GET_BUILD_TIMESTAMP>")
        protocolGetBuildTimestamp();
    else if (tag == "<LAUNCH_BOOTLOADER>")
        protocolLaunchBootloader();
    else
        sendError("UNKNOWN_COMMAND");
}

// ---------------------------------------------------------------------------------------------- //

void RelayBoard::onHostDataOverflow()
{
    sendError("DATA_OVERFLOW");
}

// ---------------------------------------------------------------------------------------------- //

void RelayBoard::onRelayFault()
{
    HAL_GPIO_WritePin(STATUS_GPIO_Port, STATUS_Pin, GPIO_PIN_RESET);
}

// ---------------------------------------------------------------------------------------------- //

void RelayBoard::protocolGetFaultMask()
{
    sendResponse(String::format("<FAULT_MASK> 0x%04x", m_relayManager.getFaultMask()));
}

// ---------------------------------------------------------------------------------------------- //

void RelayBoard::protocolSetRelayState(const String& data, size_t tokenCount)
{
    try {
        checkTokenCount(tokenCount, 3);

        const uint8_t index = toIndex(data.getToken(TokenSeparator, 1));
        const RelayState state = toRelayState(data.getToken(TokenSeparator, 2));

        m_relayManager.setState(index, state);
        sendResponse("<OK>");
    }
    catch (const std::exception& e) {
        sendError(e.what());
    }
}

// ---------------------------------------------------------------------------------------------- //

void RelayBoard::protocolGetRelayState(const String& data, size_t tokenCount)
{
    try {
        checkTokenCount(tokenCount, 2);

        const uint8_t index = toIndex(data.getToken(TokenSeparator, 1));
        const RelayState state = m_relayManager.getState(index);

        sendResponse("<RELAY_STATE>", (state == RelayState::On) ? "ON" : "OFF");
    }
    catch (const std::exception& e) {
        sendError(e.what());
    }
}

// ---------------------------------------------------------------------------------------------- //
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

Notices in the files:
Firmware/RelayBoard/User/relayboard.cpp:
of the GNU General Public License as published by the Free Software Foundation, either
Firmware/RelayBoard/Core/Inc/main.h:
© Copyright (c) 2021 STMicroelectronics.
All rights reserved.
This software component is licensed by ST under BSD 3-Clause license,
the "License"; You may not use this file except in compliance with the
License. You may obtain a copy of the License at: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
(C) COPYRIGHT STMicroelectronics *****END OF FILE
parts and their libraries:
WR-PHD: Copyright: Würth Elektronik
